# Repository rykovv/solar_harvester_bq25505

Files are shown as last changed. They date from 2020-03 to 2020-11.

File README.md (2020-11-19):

# Solar Harvester v1.0_m1

Solar harvesting power supply board based on TI BQ25505 PMIC with MPPT functionality configured for tracking 80% of the PV input. The board provides voltage/current measurement IC (INA226) intended for measurement of the PV input and a fuel gauge system based on MAX17040 IC to check and monitor battery state.

## Table of Contents ##

[[_TOC_]]

## Rev1 manufactured and assembled

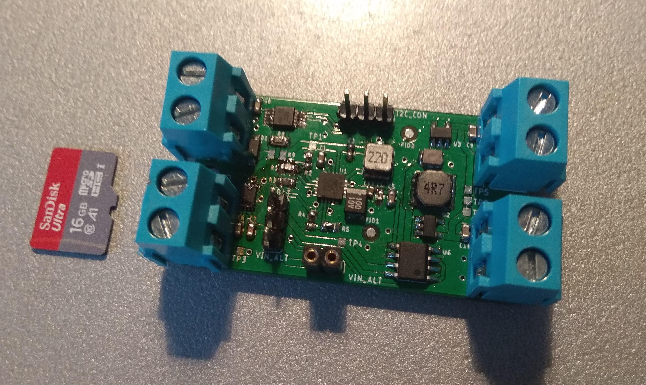
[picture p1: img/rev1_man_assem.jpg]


## Rev2 simulated

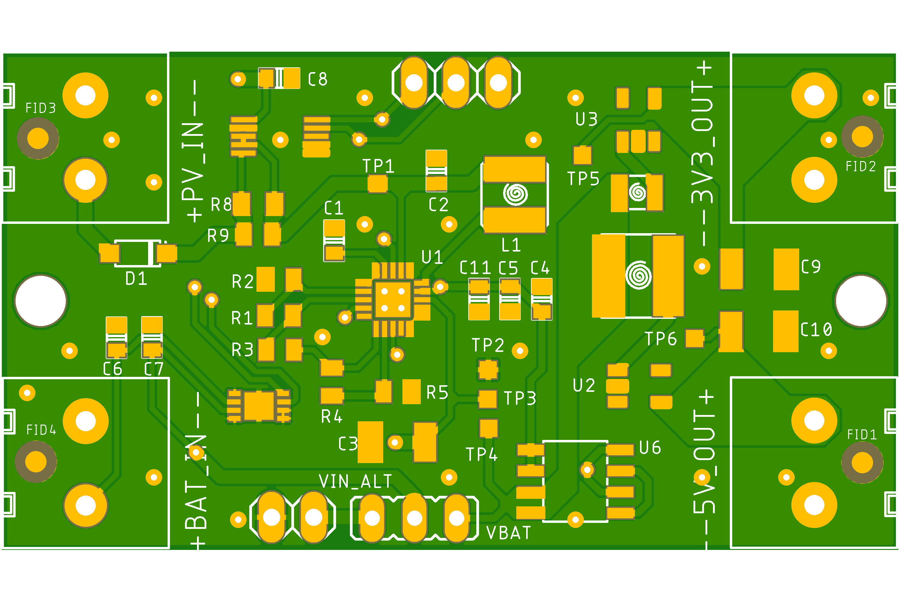
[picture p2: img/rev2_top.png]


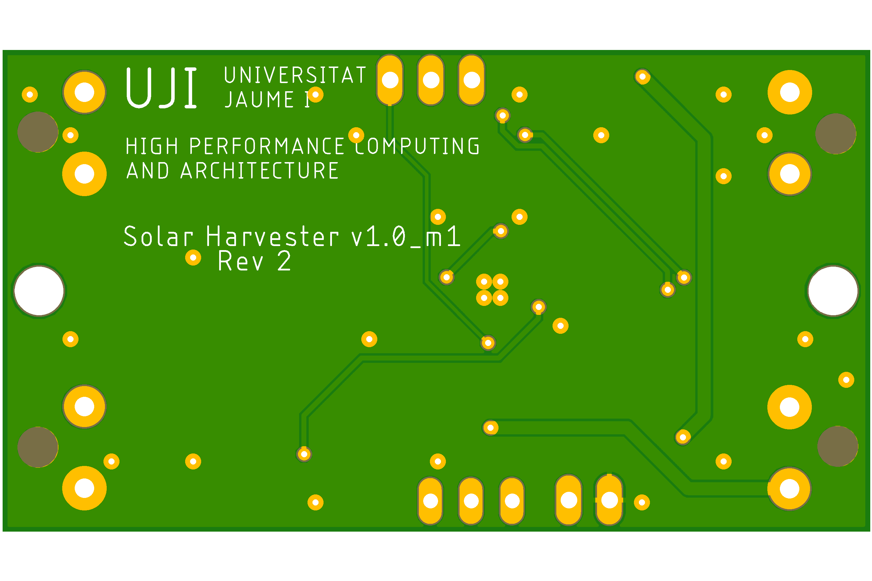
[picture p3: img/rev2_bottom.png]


## Detailed Overview

The BQ25505 was created for special needs of ultra low power applications. Therefore, it is designed for extract uW and mW of power generated from multiple energy harvesting sources. The board configuration suits only for solar power applications.

Once a PV pannel and Lipo battery are connected to the board and load capacitors are charged (>=1.8V) the main boost charger starts working extracting energy from the PV pannel. The ouput power is driven based on VBAT_OK threshold (3.3V) which is set based on R~ok1-3~ resistors. If the attached battery voltage is less then VBAT_OK, than only charging circuitry will work. This way the battery is saved from being damaged by undervoltage condition. Once the battery voltage rises up to VBAT_OK_HYST (3.7V), the load will be connected to the battery again. The BQ25505 provides overvoltage protection functionality set based on R~ov1,2~ resistors. That is, when the battery voltage reaches VBAT_OV voltage (4.2V) the main boost charger cease charging and only monitors voltage levels. Summing up, the BQ25505 will charge the storage element always unless its voltage is less than VBAT_OV. Refer to the Battery over-voltage, under-voltage and operating range section for examining concrete values calculation.

There is a possibility for supercap input energy storage instead of the Lipo battery. The maximum voltage for the supercap must be 5V. This modification implies changes in VBAT_OK, VBAT_OK_HYST, and VBAT_OV threasholds; and R~ok1-3~ resistors must be reselected accordingly. Refer to the BQ25505 datasheet to see corresponding formulas and equations (Section 8.2.1.2 Detailed Design Procedure).

Adjust CSTOR load capacitors depending on energy storage voltage. Remove C11 if VBAT_SEC < 3.0V.

## Specifications

Input:
 - PV panel 5V, 150mA
 - Lipo 3.7V battery

Output:
 - 3.3V, 1.2A
 - 5V, 1.8A

Maximum charging curerrent is 100mA.

## ICs
 - BQ25505
 - TPS613221A (3.3V)
 - TPS613222A (5V)
 - INA226
 - MAX17040
 - DMP3085LSD (dual pmos)

## Data Out - I^2^C
In order to extract information from the voltage/current measurement IC and the fuel gauge the proper I^2^C connection is needed. External pin headers fulfill this purpose. Note the internal I^2^C bus is **not pulled up**. Make sure the I^2^C bus from your main MCU board pulls up the bus.

## Battery over-voltage, under-voltage and operating range

### Over-voltage

Battery over-voltage protection is determined by R1 and R2 resistors according to 7.3.3

**VBAT_OV** = 3/2 * VBIAS * (1 + R1/R2)

Since, VBIAS is internally set to 1.21V, we have

VBAT_OV = 3/2 * 1.21V * (1 + 7.32M/5.62M) = **4.179V ~= 4.2V**

### Under-voltage

Battery under-voltage is internally set to 1.95V (see 7.3.2), hence being to suitable for the application, the push-pull multiplexer drivers (see 7.3.5) were used for the purpose. According to VBAT_OK and VBAT_OK_HYST values (see Operating range section).

### Operating range

The battery operating range is established by R3, R4, and R5 resistors which determine VBAT_OK and VBAT_OK_HYST values. According to the selected resistors values,

**VBAT_OK** = VBIAS * (1 + R4/R5) = 1.21V * (1 + 7.5M/4.3M) = **3.32V**

and

**VBAT_OK_HYST** = VBIAS * (1 + [R4 + R3]/R5) = 1.21V * (1 + [7.5M + 1.2M]/4.3M) = **3.658V**

## Issues

Despite all values of resistors R~ok1-3~ and R~ov1,2~ were correctly calculated (see 3.7V 860mAh Li-po battery and Battery over-voltage, under-voltage and operating range section) BQ25505 does not behave as expected and presents serious instabilities incompatible with deployment in real applications. When the battery is fully charged and attached, on one hand, and there is enough PV power input to start the circuitry, on the other hand, the BQ25505 starts working as expected until the battery is discharged (voltage below VBAT_OK). When the battery is half-discharged (voltage about VBAT_OK_HYST), and independently of the PV power input, VSTOR is unable to give stable output. What happens is when the 3.3V & 5V voltage regulators reach predefined output levels and the load starts to consume power (especially when the power is greater than 200mA, perhaps max transitory current in this state is much lower), the BQ25505 switches constantly on and off #VBAT_SEC_ON for a couple of milliseconds. It makes impossible to provide enough power for stable MCU launching.

A potential solution for this drawback is to substitute the current Under-voltage protection scheme with a battery management IC that would be in charge of over- and under-voltage protection.

## Revisions

### Rev 0
### Rev 1
 - Components with 0603 metric footprint were substituted by 0603 imperial
### Rev 2
 - Board size increased to 30x55
 - Changed C3 footprint to 3528, C4 and C11 to 1608
 - Changed C9 and C10 to 100u 3528
 - Rewired PCB
 - Components font size increased to 32mil

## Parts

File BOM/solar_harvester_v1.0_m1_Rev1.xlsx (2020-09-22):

Company: | University Jaume I |  |  |  | Project Name: | Solar Harvester v1.0_m1 |  | PCB Options :
Contact: | Vladislav Rykov |  |  |  | Order / Task:
Address: | Castellón - Spain Shippment: Castellón - Spain |  |  |  |  |  |  | PCB Size |  | 43.2 x 68.6mm
 |  |  |  |  |  |  |  | Layers: |  | 2
 |  |  |  |  |  |  |  | Thickness: |  | 1.6mm
 |  |  |  |  |  |  |  | Solder Mask Color: |  | Green
Tel: | +34 642411134 |  |  |  |  |  |  | Surface Finish: |  | HASL(Lead Free)
Email: | rykov@uji.es |  |  |  |  |  |  | Copper Weight: |  | 1oz.
# | Reference | Qty | Value | Manufacturer | MPN | Description | Package | SMD/THT | Pins /Pads per Component | Distributor | Distributor SKU | More Details
1 | JP1, JP4 | 2 |  | Amphenol Commercial Products | G800LQ305018EU | Headers & Wire Housings Pin Header 2.54mm Pitch STR DIP,1x3Pin |  | THT | 3 | Mouser | 523-G800LQ305018EU
2 | JP3 | 1 |  | Preci-dip | 801-87-002-10-001101 | Headers & Wire Housings |  | THT | 2 | Mouser | 437-8018700210001101
3 | R9 | 1 | 0 | Vishay / Dale | CRCW06030000Z0EAC | Thick Film Resistors 1/10Watt 0ohms Commercial Use |  | SMD | 2 | Mouser | 71-CRCW06030000Z0EAC
4 | C1, C7 | 2 | 0.01u | Wurth Elektronik | 885012206040 | Multilayer Ceramic Capacitors MLCC - SMD/SMT WCAP-CSGP 0.01uF 0603 10% 16V MLCC |  | SMD | 2 | Mouser | 710-885012206040
5 | C5, C8 | 2 | 0.1u | Wurth Elektronik | 885012206071 | Multilayer Ceramic Capacitors MLCC - SMD/SMT WCAP-CSGP 0.1uF 0603 10% 25V MLCC |  | SMD | 2 | Mouser | 710-885012206071
6 | C3 | 1 | 100u | AVX | F931A107KBA | Tantalum Capacitors - Solid SMD 10V 100uF 10% 1211 ESR= 1.2 Ohms |  | SMD | 2 | Mouser | 647-F931A107KBA
8 | C11 | 1 | 10u | Taiyo Yuden | JMK107ABJ106MA-T | Multilayer Ceramic Capacitors MLCC - SMD/SMT 10uF 6.3V X5R +/-20% 0603 Gen Purp |  | SMD | 2 | Mouser | 963-JMK107ABJ106MA-T
9 | R6 | 1 | 1k | Vishay / Dale | CRCW06031K00FKEAC | Thick Film Resistors 1/10Watt 1Kohms 1% Commercial Use |  | SMD | 2 | Mouser | 71-CRCW06031K00FKEAC
10 | C6 | 1 | 1u | Yageo | CC0603KRX5R8BB105 | Multilayer Ceramic Capacitors MLCC - SMD/SMT 1.0uF 25V X5R 10% |  | SMD | 2 | Mouser | 603-CC603KRX5R8BB105
11 | C9, C10 | 2 | 22u | Murata Electronics | GRM188R61A226ME15D | Multilayer Ceramic Capacitors MLCC - SMD/SMT 0603 22uF 10volts *Derate Voltage/Temp |  | SMD | 2 | Mouser | 81-GRM188R61A226ME5D
12 | L1 | 1 | 22u | Wurth Elektronik | 74404043220A | Fixed Inductors WE-LQS 4025 22uH 1.11A 200mOhms |  | SMD | 2 | Mouser | 710-74404043220A
13 | R8 | 1 | 2m | IRC / TT Electronics | LRCS0805-R56JT5 | Current Sense Resistors - SMD 0805 .56 Ohms 5% |  | SMD | 2 | Mouser | 756-LRCS0805-R56JT5
14 | C2, C4 | 2 | 4u7 | Taiyo Yuden | LMK105BBJ475MVLF | Multilayer Ceramic Capacitors MLCC - SMD/SMT 0402 10V 4.7uF 20% X5R |  | SMD | 2 | Mouser | 963-LMK105BBJ475MVLF
15 | L3 | 1 | 4u7 | Taiyo Yuden | MAMK2520T4R7M | Fixed Inductors 1008 4.7uH 260mOhms +/-20%Tol 1.3A HiCur |  | SMD | 2 | Mouser | 963-MAMK2520T4R7M
16 | L2 | 1 | 4u7 | Bournes | SRN5020TA-4R7M | Fixed Inductors 4.7uH 20% 2.4A |  | SMD | 2 | Mouser | 652-SRN5020TA-4R7M
17 | R2 | 1 | 5.62M | Vishay / Dale | CRCW06035M62FKEA | Thick Film Resistors - SMD 1/10watt 5.62Mohms 0.01 |  | SMD | 2 | Mouser | 71-CRCW06035M62FKEA
18 | R1 | 1 | 7.32M | Vishay / Dale | CRCW06037M32FKEA | Thick Film Resistors - SMD 1/10watt 7.32Mohms 0.01 |  | SMD | 2 | Mouser | 71-CRCW06037M32FKEA
19 | R3 | 1 | 1.2M | Vishay / Dale | CRCW06031M20FKEA | Thick Film Resistors - SMD 1/10watt 1.2Mohms 1% |  | SMD | 2 | Mouser | 71-CRCW06031M20FKEA
20 | R4 | 1 | 7.5M | Vishay / Dale | CRCW06037M50FKEA | Thick Film Resistors - SMD 1/10watt 7.5Mohms 1% |  | SMD | 2 | Mouser | 71-CRCW0603-7.5M-E3
21 | R5 | 1 | 4.3M | Vishay / Dale | CRCW06034M30FKEA | Thick Film Resistors - SMD 1/10watt 4.3Mohms 1% |  | SMD | 2 | Mouser | 71-CRCW06034M30FKEA
22 | U1 | 1 | BQ25505 | Texas Instruments | BQ25505RGRR | Battery Management Ultra Low Power Harvester Pwr Mgmt |  | SMD | 21 | Mouser | 595-BQ25505RGRR
23 | 3V3_OUT, 5V_OUT, BAT_IN, PV_IN | 4 |  | CUI Devices | TB007-508-02BE | Fixed Terminal Blocks Terminal block, screw type, 5.08, PCB mount |  | THT | 2 | Mouser | 490-TB007-508-02BE
24 | U6 | 1 | DMP3085LSD | Diodes Incorporated | DMP3085LSD-13 | MOSFET P-Ch ENH FET -30V 70mOhm -10V -3.9A |  | SMD | 8 | Mouser | 621-DMP3085LSD-13
25 | U5 | 1 | INA226 | Texas Instruments | INA226AIDGSR | Current & Power Monitors & Regulators Hi-Side Msmt,Bi-Dir Current/Pwr Mon | MSOP-10 / VSSOP | SMD | 10 | Mouser | 595-INA226AIDGSR
26 | D1 | 1 | SD101CW RH | Taiwan Semiconductor | SD101CW RH | Schottky Diodes & Rectifiers 15mA 50 Volt 400mW |  | SMD | 2 | Mouser | 821-SD101CWRH
27 | U4 | 1 | MAX17040 | Maxim Integrated | MAX17040G+T | Battery Management Compact, Low-Cost 1S/2S Fuel Gauges | 8 TDFN-EP | SMD | 9 | Mouser | 700-MAX17040G+T
28 | U2 | 1 | TPS613222ADBVR | Texas Instruments | TPS613222ADBVR | IC REG BOOST 5V 2.5A SOT23-5 | SOT23-5 | SMD | 5 | Mouser | 595-TPS613222ADBVR
29 | U3 | 1 | TPS613221ADBVR | Texas Instruments | TPS613221ADBVR | IC REG BOOST 3.3V 1.6A SOT23-5 | SOT23-5 | SMD | 5 | Mouser | 595-TPS613221ADBVR
28
 |  |  |  |  |  |  | THT | 7 | 16
 |  |  |  | *Generic parts can be replaced for other components with same features. The MPN is additional information. |  |  | SMD | 29 | 104
 |  |  |  |  |  |  | TOTAL | 36 | 120

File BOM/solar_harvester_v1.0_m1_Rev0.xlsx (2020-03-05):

Company: | University Jaume I |  |  |  | Project Name: | Solar Harvester v1.0_m1 |  | PCB Options :
Contact: | Vladislav Rykov |  |  |  | Order / Task:
Address: | Castellón - Spain Shippment: Castellón - Spain |  |  |  |  |  |  | PCB Size |  | 43.2 x 68.6mm
 |  |  |  |  |  |  |  | Layers: |  | 2
 |  |  |  |  |  |  |  | Thickness: |  | 1.6mm
 |  |  |  |  |  |  |  | Solder Mask Color: |  | Green
Tel: | +34 642411134 |  |  |  |  |  |  | Surface Finish: |  | HASL(Lead Free)
Email: | rykov@uji.es |  |  |  |  |  |  | Copper Weight: |  | 1oz.
# | Reference | Qty | Value | Manufacturer | MPN | Description | Package | SMD/THT | Pins /Pads per Component | Distributor | Distributor SKU | More Details
1 | JP1, JP4 | 2 |  | Amphenol Commercial Products | G800LQ305018EU | Headers & Wire Housings Pin Header 2.54mm Pitch STR DIP,1x3Pin |  | THT | 3 | Mouser | 523-G800LQ305018EU
2 | JP3 | 1 |  | Preci-dip | 801-87-002-10-001101 | Headers & Wire Housings |  | THT | 2 | Mouser | 437-8018700210001101
3 | R9 | 1 | 0 | Vishay / Dale | CRCW02010000Z0ED | Thick Film Resistors - SMD 1/20watt ZEROohm Jumper 0603 |  | SMD | 2 | Mouser | 71-CRCW02010000Z0ED
4 | C1 | 1 | 0.01u | Murata Electronics | GRM033R71A103KA01D | Multilayer Ceramic Capacitors MLCC - SMD/SMT 0201 0.01uF 10volts X7R 10% |  | SMD | 2 | Mouser | 81-GRM033R71A103KA1D
5 | C5, C8 | 2 | 0.1u | Taiyo Yuden | LMK063C6104MP-F | Multilayer Ceramic Capacitors MLCC - SMD/SMT 10V 0.1uF 20% X6S 0603 |  | SMD | 2 | Mouser | 963-LMK063C6104MP-F
6 | C3 | 1 | 100u | AVX | F931A107KBA | Tantalum Capacitors - Solid SMD 10V 100uF 10% 1211 ESR= 1.2 Ohms |  | SMD | 2 | Mouser | 647-F931A107KBA
7 | C7 | 1 | 10n | Murata Electronics | GRM033R71A103KA01D | Multilayer Ceramic Capacitors MLCC - SMD/SMT 0201 0.01uF 10volts X7R 10% |  | SMD | 2 | Mouser | 81-GRM033R71A103KA1D
8 | C11 | 1 | 10u | Murata Electronics | ZRB15XR61A106ME01D | Multilayer Ceramic Capacitors MLCC - SMD/SMT |  | SMD | 2 | Mouser | 81-ZRB15XR61A106ME1D
9 | R6 | 1 | 1k | Panasonic | ERJ-1GNF1001C | Thick Film Resistors - SMD 1Kohm 1% HalogenFree AEC-Q200 0603 |  | SMD | 2 | Mouser | 667-ERJ-1GNF1001C
10 | C6 | 1 | 1u | Murata Electronics | GRM033R60J105ME11J | Multilayer Ceramic Capacitors MLCC - SMD/SMT 1UF 6.3V 20% 0603 |  | SMD | 2 | Mouser | 81-GRM033R60J105ME1J
11 | C9, C10 | 2 | 22u | Murata Electronics | GRM188R61A226ME15D | Multilayer Ceramic Capacitors MLCC - SMD/SMT 0603 22uF 10volts *Derate Voltage/Temp |  | SMD | 2 | Mouser | 81-GRM188R61A226ME5D
12 | L1 | 1 | 22uH | WURTH ELEKTRONIK | 74404043220A | FIXED IND 22UH 1.11A |  | SMD | 2 | Mouser | 710-74404043220A
13 | R8 | 1 | 2m | IRC / TT Electronics | LRCS0805-R56JT5 | Current Sense Resistors - SMD 0805 .56 Ohms 5% |  | SMD | 2 | Mouser | 756-LRCS0805-R56JT5
14 | C2, C4 | 2 | 4u7 | Taiyo Yuden | LMK105BBJ475MVLF | Multilayer Ceramic Capacitors MLCC - SMD/SMT 0402 10V 4.7uF 20% X5R |  | SMD | 2 | Mouser | 963-LMK105BBJ475MVLF
15 | L3 | 1 | 4u7 | Taiyo Yuden | MAMK2520T4R7M | FIXED IND 4.7UH 1.3A 260 MOHM |  | SMD | 2 | Mouser | 963-MAMK2520T4R7M
16 | L2 | 1 | 4u7 | Bournes | SRN5020TA-4R7M | FIXED IND 4.7UH 2.4A 60MOHM |  | SMD | 2 | Mouser | 652-SRN5020TA-4R7M
17 | R2 | 1 | 5.62M | KOA Speer | RK73H1HTTC5624F | Thick Film Resistors - SMD 1/20W 5.62M OHM 1% 200PPM |  | SMD | 2 | Mouser | 660-RK73H1HTTC5624F
18 | R1, R3, R4, R5 | 4 | 7.32M | Vishay / Dale | CRCW02017M32FNED | Thick Film Resistors - SMD 7.32M OHM 1% |  | SMD | 2 | Mouser | 71-CRCW02017M32FNED
19 | U1 | 1 | BQ25505 | Texas Instruments | BQ25505RGRR | Battery Management Ultra Low Power Harvester Pwr Mgmt |  | SMD | 21 | Mouser | 595-BQ25505RGRR
20 | 3V3_OUT, 5V_OUT, BAT_IN, PV_IN | 4 |  | CUI Devices | TB007-508-02BE | Fixed Terminal Blocks Terminal block, screw type, 5.08, PCB mount |  | THT | 2 | Mouser | 490-TB007-508-02BE
21 | U6 | 1 | DMP3085LSD | Diodes Incorporated | DMP3085LSD-13 | MOSFET P-Ch ENH FET -30V 70mOhm -10V -3.9A |  | SMD | 8 | Mouser | 621-DMP3085LSD-13
22 | U5 | 1 | INA226 | Texas Instruments | INA226AIDGSR | Current & Power Monitors & Regulators Hi-Side Msmt,Bi-Dir Current/Pwr Mon | MSOP-10 / VSSOP | SMD | 10 | Mouser | 595-INA226AIDGSR
23 | D1 | 1 | JDH2S02SL | Toshiba | JDH2S02SL,L3F | Schottky Diodes & Rectifiers High Freq Schottky .01A 10V |  | SMD | 2 | Mouser | 757-JDH2S02SLL3F
24 | U4 | 1 | MAX17040 | Maxim Integrated | MAX17040G+T | Battery Management Compact, Low-Cost 1S/2S Fuel Gauges | 8 TDFN-EP | SMD | 9 | Mouser | 700-MAX17040G+T
25 | U2 | 1 | TPS613222ADBVR | Texas Instruments | TPS613222ADBVR | IC REG BOOST 5V 2.5A SOT23-5 | SOT23-5 | SMD | 5 | Mouser | 595-TPS613222ADBVR
26 | U3 | 1 | TPS613221ADBVR | Texas Instruments | TPS613221ADBVR | IC REG BOOST 3.3V 1.6A SOT23-5 | SOT23-5 | SMD | 5 | Mouser | 595-TPS613221ADBVR
26
 |  |  |  |  |  |  | THT | 7 | 16
 |  |  |  | *Generic parts can be replaced for other components with same features. The MPN is additional information. |  |  | SMD | 29 | 104
 |  |  |  |  |  |  | TOTAL | 36 | 120

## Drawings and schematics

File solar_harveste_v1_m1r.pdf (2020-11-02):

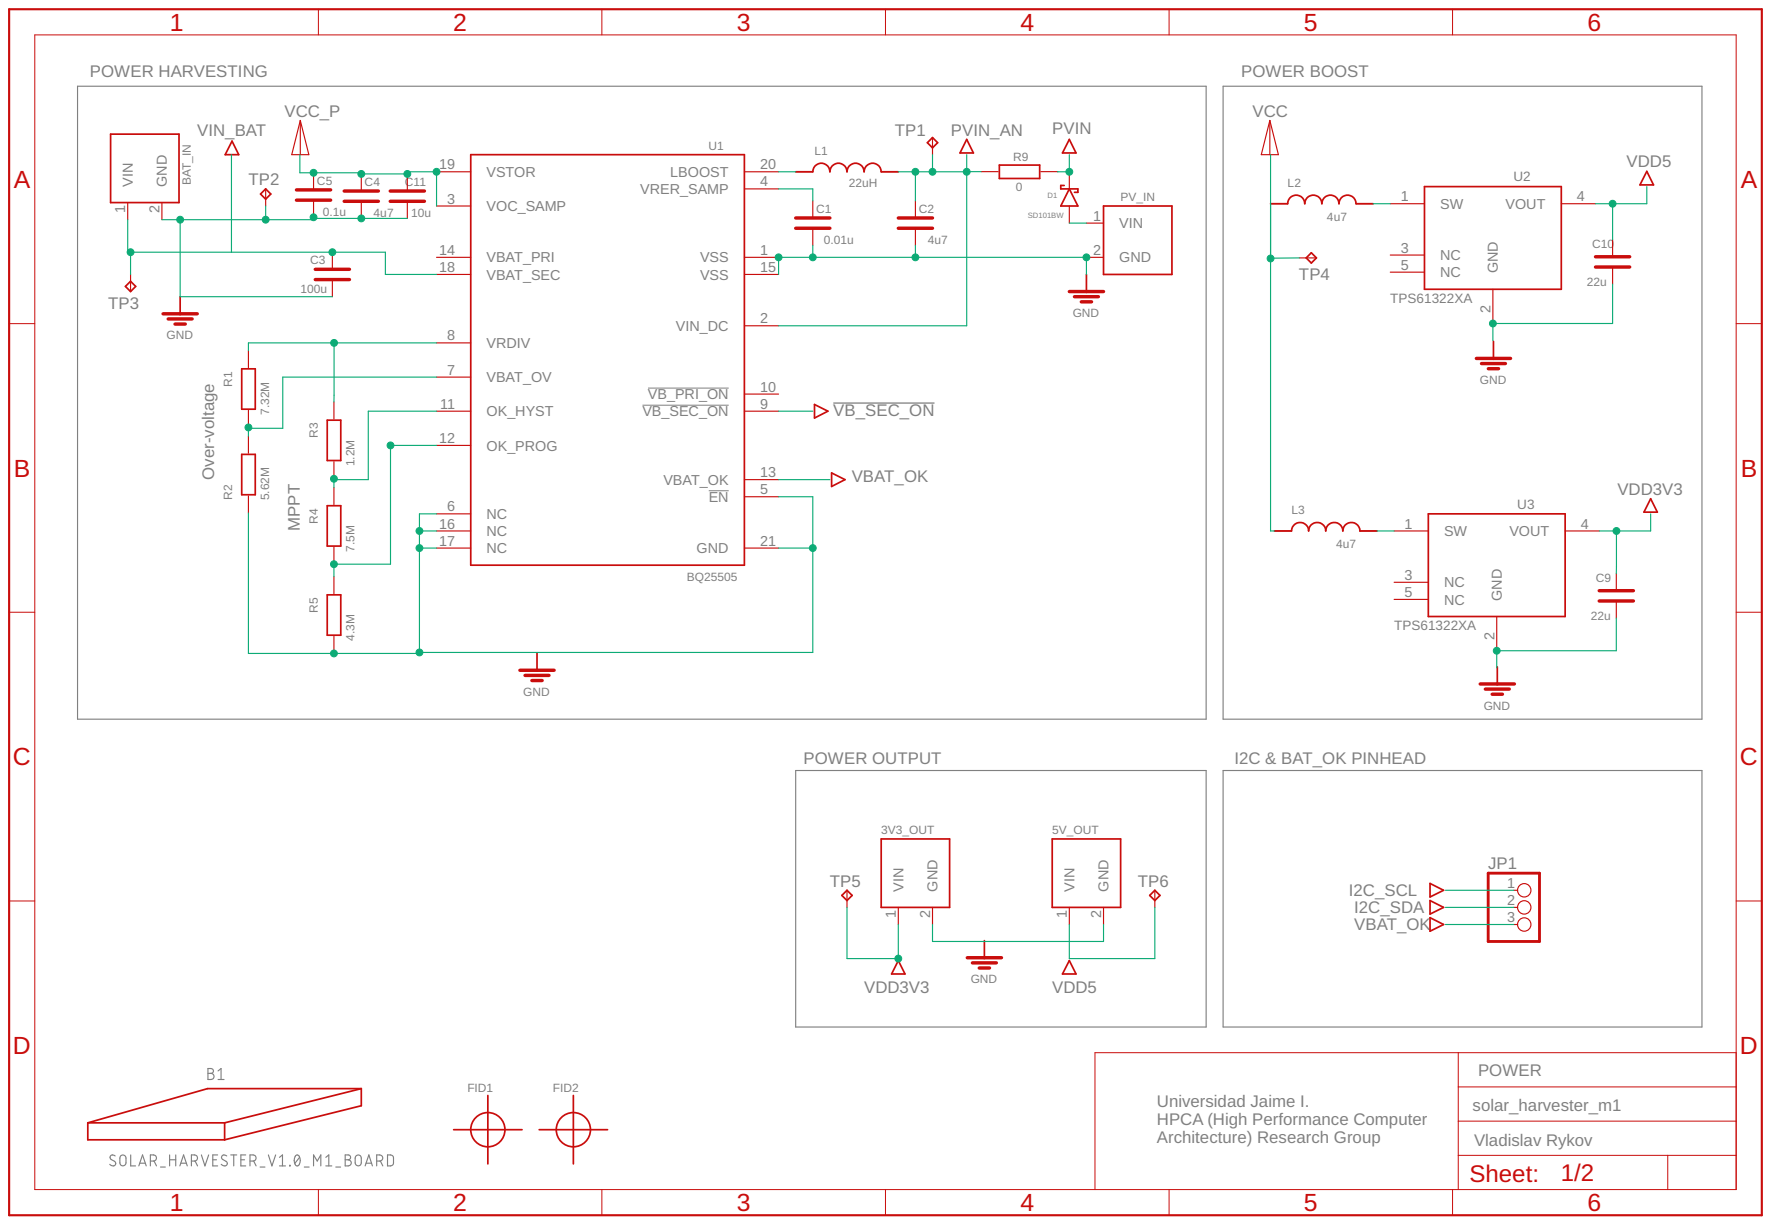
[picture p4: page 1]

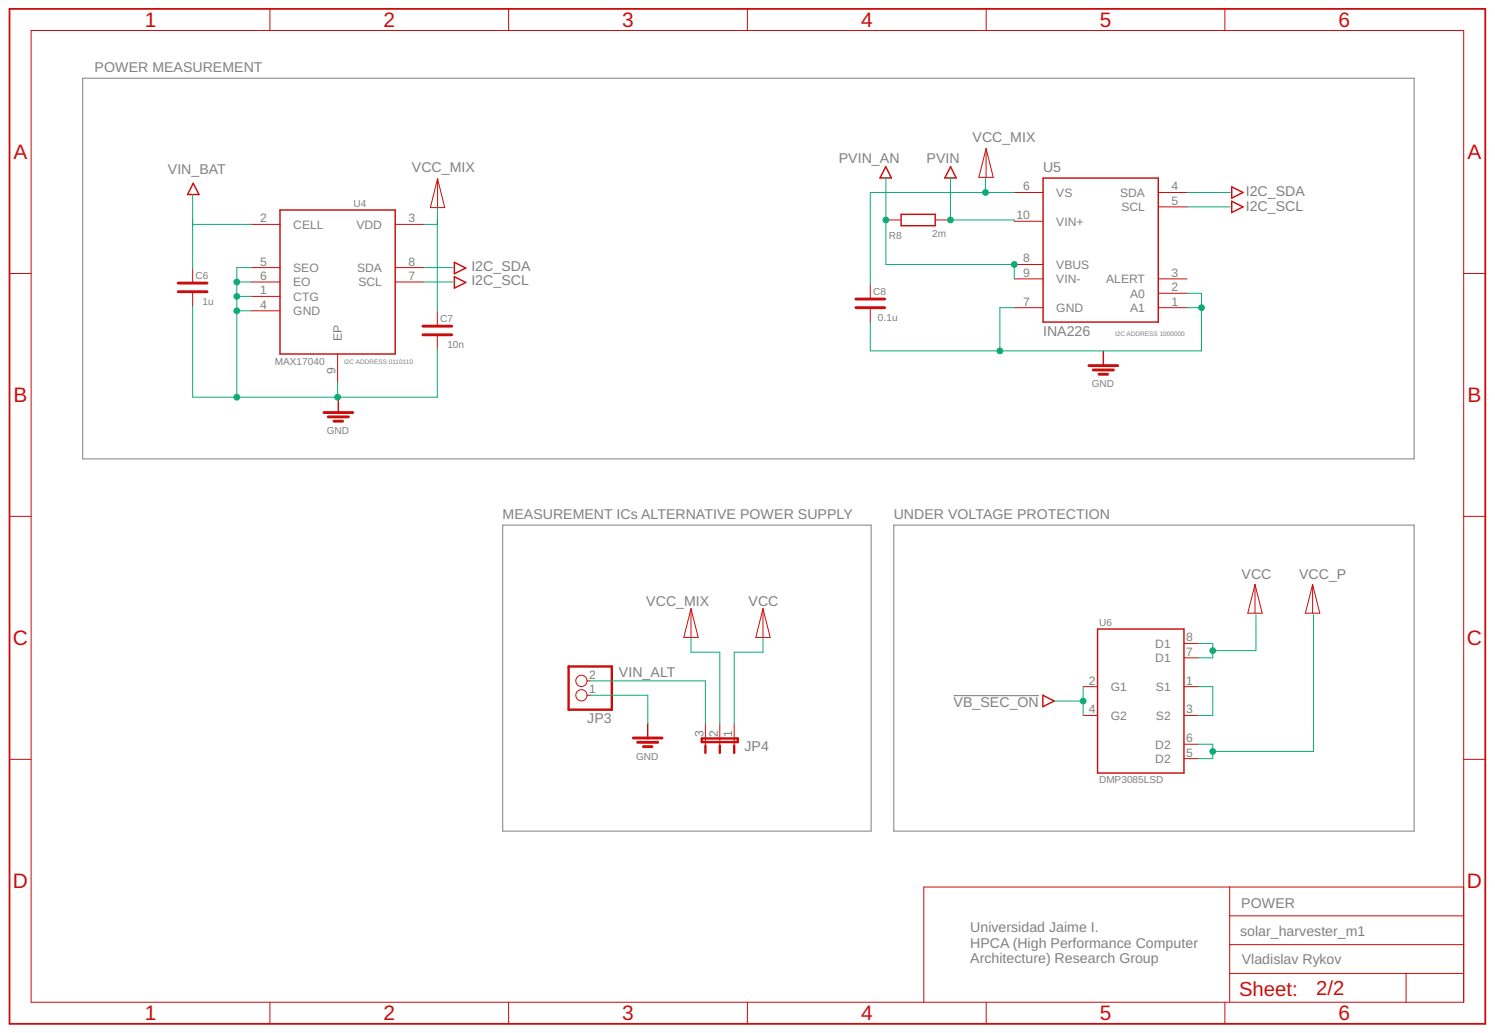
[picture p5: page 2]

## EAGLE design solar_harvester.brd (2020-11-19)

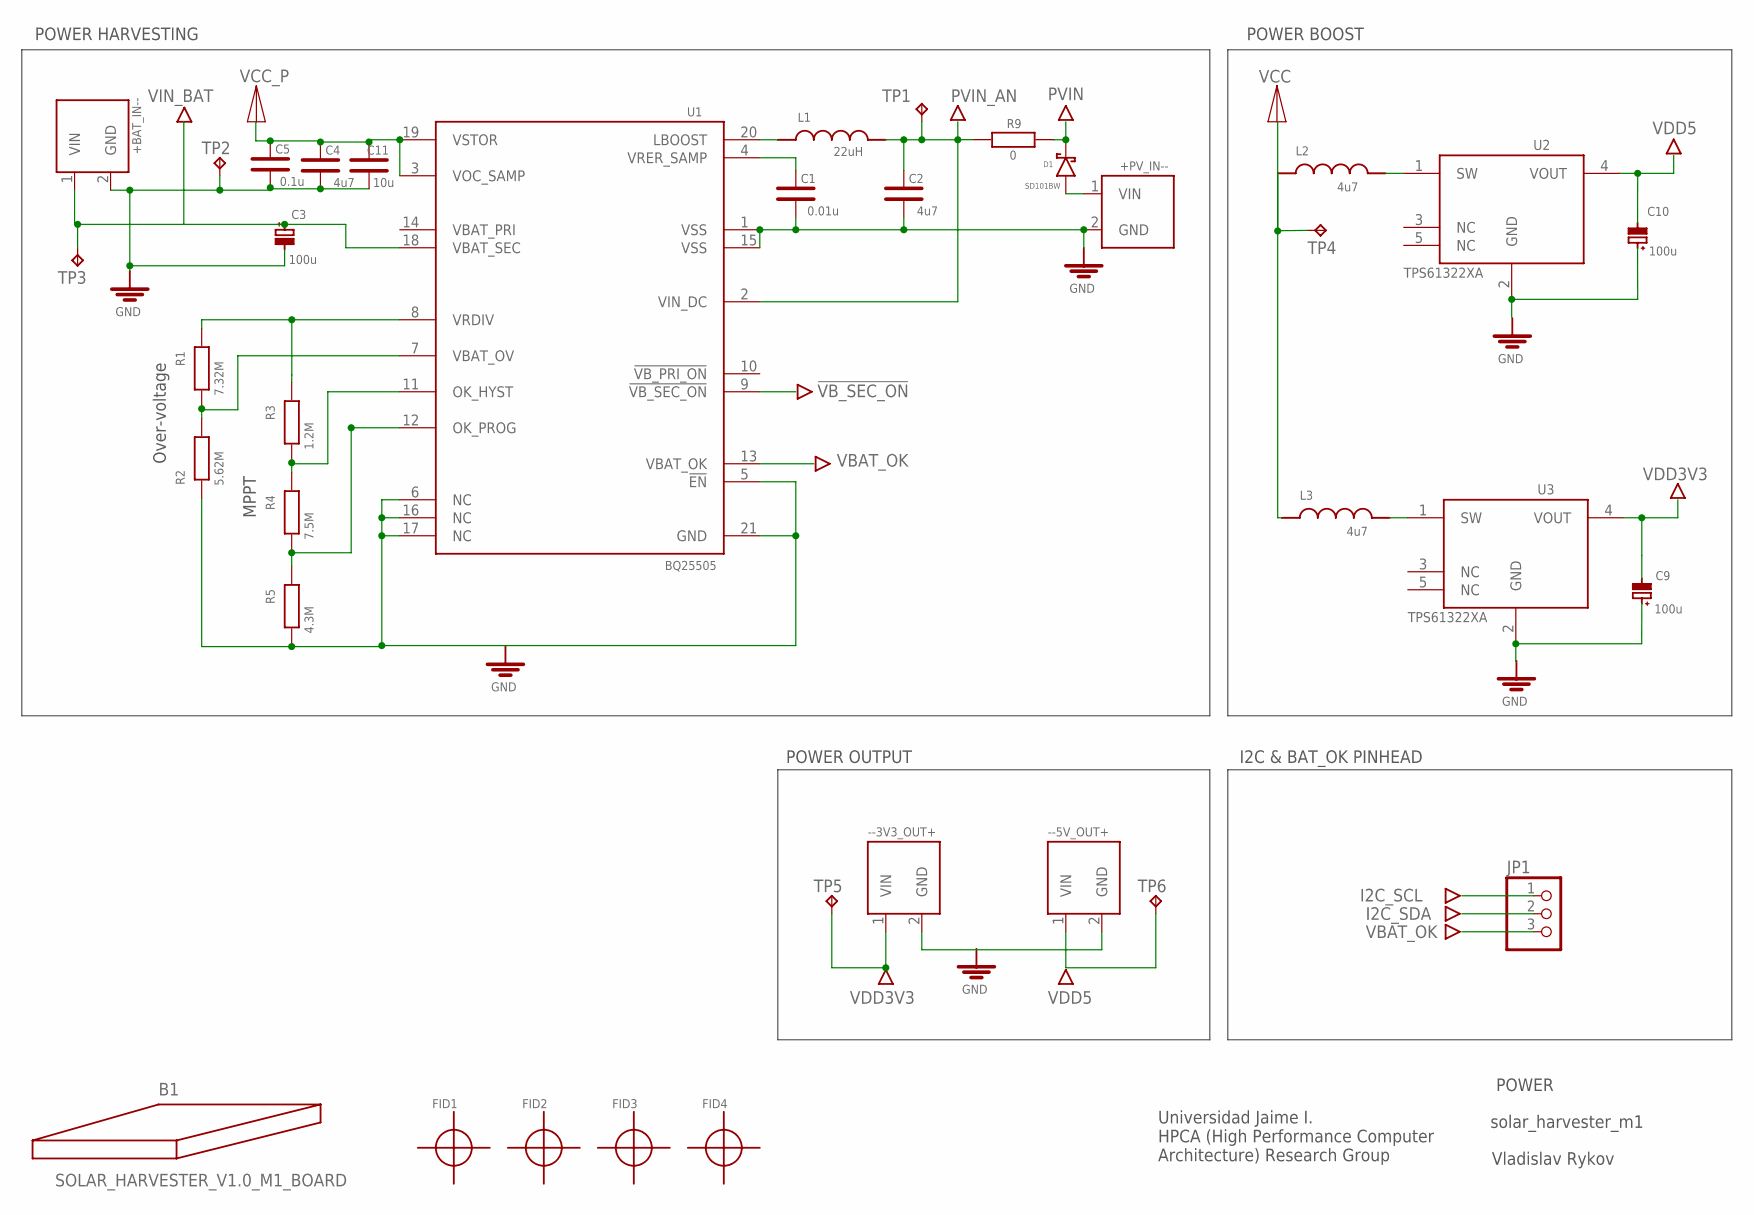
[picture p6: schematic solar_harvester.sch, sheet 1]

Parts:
+BAT_IN--: CONN_SCEW_TYPE_2P; CONN_SCREW_TYPE_2P
+PV_IN--: CONN_SCEW_TYPE_2P; CONN_SCREW_TYPE_2P
--3V3_OUT+, --5V_OUT+: CONN_SCEW_TYPE_2P; CONN_SCREW_TYPE_2P
B1: SOLAR_HARVESTER_V1.0_M1_BOARD; SOLAR_HARVESTER_V1.0_M1_FOOTPRINT
C1: 0.01u; 1608_FOOTPRINT
C2, C4: 4u7; 1608_FOOTPRINT
C3, C9, C10: 100u; 3528_TAN_FOOTPRINT
C5: 0.1u; 1608_FOOTPRINT
C11: 10u; 1608_FOOTPRINT
D1: SD101BW; SOD-123
FID1, FID2, FID3, FID4: FIDUCIAL_25
JP1: PINHD-1X3; 1X03
L1: 22uH; FIXED_4040_FOOTPRINT
L2: 4u7; FIXED_5050_FOOTPRINT
L3: 4u7; FIXED_2520_FOOTPRINT
R1: 7.32M; RESISTOR_1608_FOOTPRINT
R2: 5.62M; RESISTOR_1608_FOOTPRINT
R3: 1.2M; RESISTOR_1608_FOOTPRINT
R4: 7.5M; RESISTOR_1608_FOOTPRINT
R5: 4.3M; RESISTOR_1608_FOOTPRINT
R9: 0; RESISTOR_1608_FOOTPRINT
TP1, TP2, TP3, TP4, TP5, TP6: TPTP10SQ; TP10SQ
U1: BQ25505; BQ25505_FOOTPRINT
U2, U3: TPS61322XA; TPS61322XA_FOOTPRINT

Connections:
!VB_SEC_ON!: U1.9 (!VB_SEC_ON!); also elsewhere on the board
GND: +BAT_IN--.2 (GND), +PV_IN--.2 (GND), --3V3_OUT+.2 (GND), --5V_OUT+.2 (GND), C1.2, C2.2, C3.2, C4.2, C5.2, C9.1, C10.1, C11.2, R2.1, R5.1, TP2.TP, U1.1 (VSS), U1.5 (!EN!), U1.6 (NC), U1.15 (VSS), U1.16 (NC), U1.17 (NC), U1.21 (GND), U2.2 (GND), U3.2 (GND); also elsewhere on the board
I2C_SCL: JP1.1; also elsewhere on the board
I2C_SDA: JP1.2; also elsewhere on the board
unnamed: L1.1, U1.20 (LBOOST)
unnamed: C1.1, U1.4 (VRER_SAMP)
unnamed: R1.2, R3.2, U1.8 (VRDIV)
unnamed: R1.1, R2.2, U1.7 (VBAT_OV)
unnamed: R3.1, R4.2, U1.11 (OK_HYST)
unnamed: R4.1, R5.2, U1.12 (OK_PROG)
unnamed: +PV_IN--.1 (VIN), D1.2
unnamed: L3.2, U3.1 (SW)
unnamed: L2.2, U2.1 (SW)
PVIN: D1.1, R9.2; also elsewhere on the board
PVIN_AN: C2.1, L1.2, R9.1, TP1.TP, U1.2 (VIN_DC); also elsewhere on the board
VBAT_OK: JP1.3, U1.13 (VBAT_OK)
VCC: L2.1, L3.1, TP4.TP; also elsewhere on the board
VCC_P: C4.1, C5.1, C11.1, U1.3 (VOC_SAMP), U1.19 (VSTOR); also elsewhere on the board
VDD3V3: --3V3_OUT+.1 (VIN), C9.2, TP5.TP, U3.4 (VOUT)
VDD5: --5V_OUT+.1 (VIN), C10.2, TP6.TP, U2.4 (VOUT)
VIN_BAT: +BAT_IN--.1 (VIN), C3.1, TP3.TP, U1.18 (VBAT_SEC); also elsewhere on the board

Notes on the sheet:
POWER HARVESTING
POWER BOOST
POWER
solar_harvester_m1
Universidad Jaime I. HPCA (High Performance Computer Architecture) Research Group
Vladislav Rykov
I2C & BAT_OK PINHEAD
POWER OUTPUT
Over-voltage
MPPT

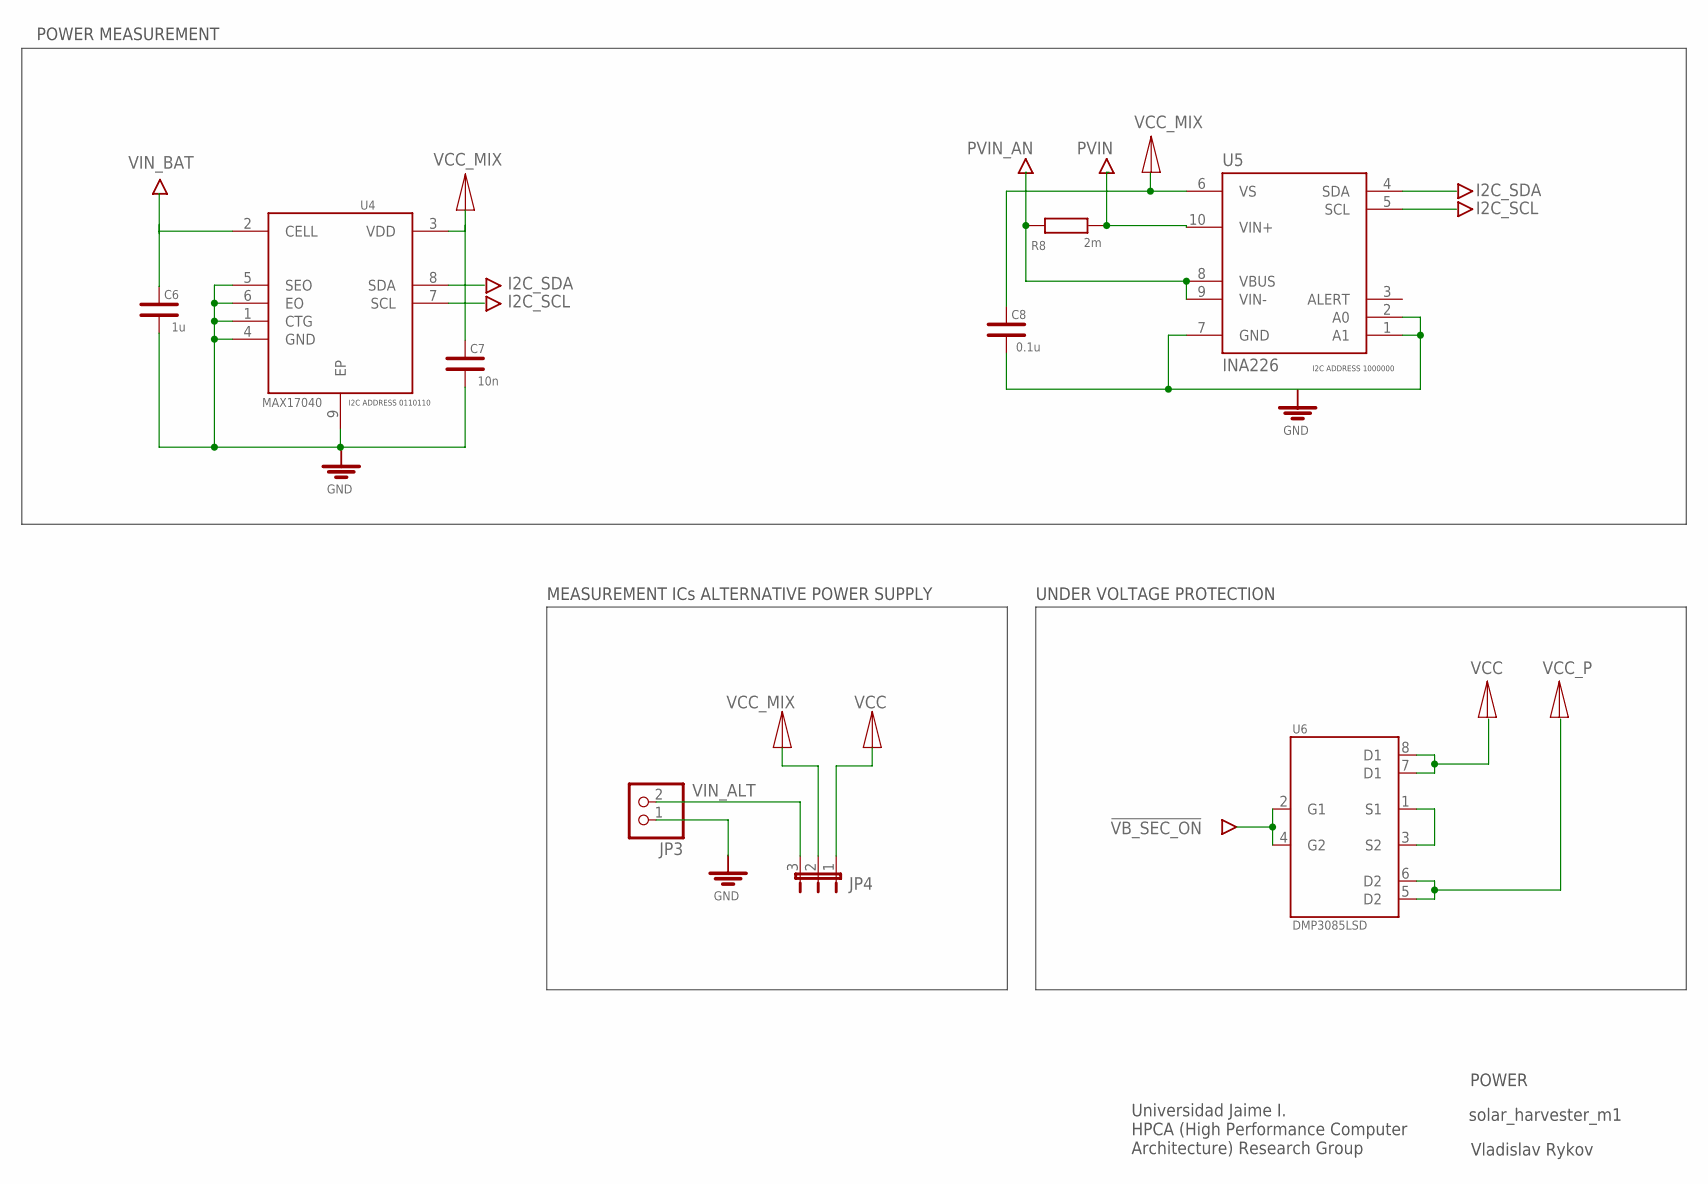
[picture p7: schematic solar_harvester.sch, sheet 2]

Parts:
C6: 1u; 1608_FOOTPRINT
C7: 10n; 1608_FOOTPRINT
C8: 0.1u; 1608_FOOTPRINT
JP3: PINHD-1X2; 1X02
JP4: JP2E; JP2
R8: 2m; RESISTOR_2012_FOOTPRINT
U4: MAX17040; MAX17040G+T_FOOTPRINT
U5: INA226; INA226_FOOTPRINT
U6: DMP3085LSD; SO-8

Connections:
!VB_SEC_ON!: U6.2 (G1), U6.4 (G2); also elsewhere on the board
GND: C6.2, C7.2, C8.2, JP3.1, U4.1 (CTG), U4.4 (GND), U4.5 (SEO), U4.6 (EO), U4.9 (EP), U5.1 (A1), U5.2 (A0), U5.7 (GND); also elsewhere on the board
I2C_SCL: U4.7 (SCL), U5.5 (SCL); also elsewhere on the board
I2C_SDA: U4.8 (SDA), U5.4 (SDA); also elsewhere on the board
unnamed: U6.1 (S1), U6.3 (S2)
PVIN: R8.2, U5.10 (VIN+); also elsewhere on the board
PVIN_AN: R8.1, U5.8 (VBUS), U5.9 (VIN-); also elsewhere on the board
VCC: JP4.1, U6.7 (D1), U6.8 (D1); also elsewhere on the board
VCC_MIX: C7.1, C8.1, JP4.2, U4.3 (VDD), U5.6 (VS)
VCC_P: U6.5 (D2), U6.6 (D2); also elsewhere on the board
VIN_ALT: JP3.2, JP4.3
VIN_BAT: C6.1, U4.2 (CELL); also elsewhere on the board

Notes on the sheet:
I2C ADDRESS 1000000
POWER
solar_harvester_m1
POWER MEASUREMENT
I2C ADDRESS 0110110
Universidad Jaime I. HPCA (High Performance Computer Architecture) Research Group
Vladislav Rykov
UNDER VOLTAGE PROTECTION
MEASUREMENT ICs ALTERNATIVE POWER SUPPLY

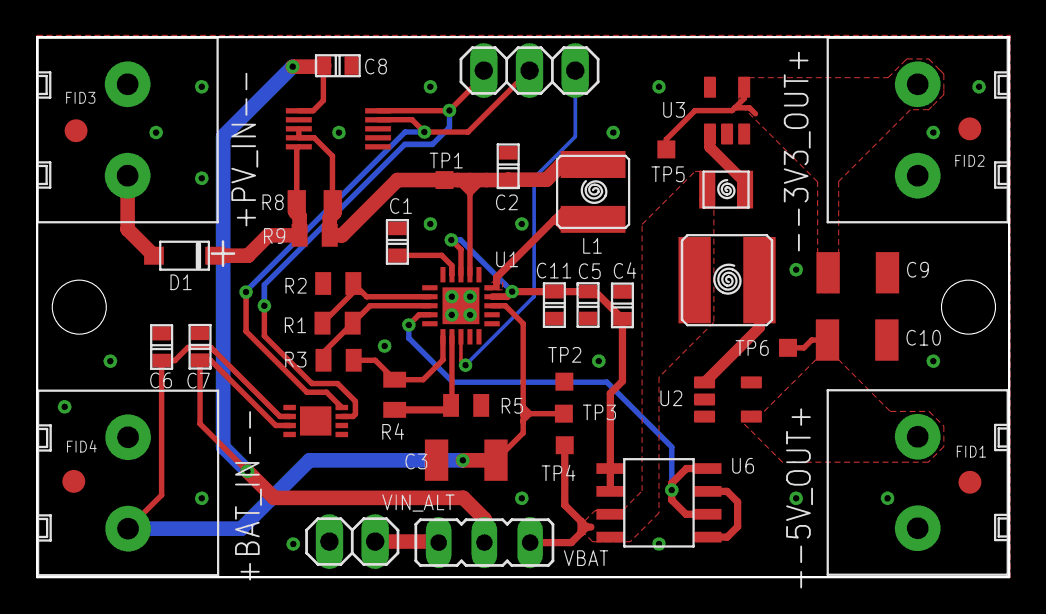
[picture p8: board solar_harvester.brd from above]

Board: 2 copper layers, 54.0 x 30.0 mm, 46 parts (0 on the bottom side), 24 nets.

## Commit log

2019-11-27 schematic complete v01. Caps and diode selection needed
    [solar_harvester.sch]
2019-11-28 board routing started
    [solar_harvester.brd, solar_harvester.sch]
2019-11-29 bq25505, both tps622, max17004 routed
    [solar_harvester.brd, solar_harvester.sch]
2019-12-02 routing complete without battery under-voltage protection
    [solar_harvester.brd, solar_harvester.sch]
2019-12-02 resized board, routing almost finished
    [solar_harvester.brd, solar_harvester.sch]
2019-12-02 Routing done, without uv protection
    [solar_harvester.brd, solar_harvester.sch]
2019-12-02 uv added schematic
    [solar_harvester.brd, solar_harvester.sch]
2019-12-02 uv routed done
    [solar_harvester.brd, solar_harvester.sch]
2019-12-03 readme added
    [solar_harvester.brd]
2019-12-03 checked pad sizes, embellished board
    [solar_harvester.brd, solar_harvester.sch]
2019-12-11 tps, fids added, todo:rev gnd, pass grc
    [solar_harvester.brd, solar_harvester.sch]
2019-12-11 alt measurement ics vin added, drc & gnd rev done
    [solar_harvester.brd, solar_harvester.sch]
2019-12-13 input power signs added
    [solar_harvester.brd]
2019-12-16 final BOM Rev0 composed, layout adjust
    Some caps sizes were changed due to vol/dimension issues
    [Copy of BomTemplate.xls, solar_harvester.brd, solar_harvester.sch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]
2020-01-15 BOM revised, gerbers generated
    [mouser copy-paste.xlsx, solar_harvester.brd, solar_harvester_v1.0_m1_Rev0.xlsx]
2020-01-21 desc minor modif
    [mouser copy-paste.xlsx]
2020-03-05 increase comps sizes -> pcb reruting (in progress)
    [solar_harvester.brd, solar_harvester.sch, solar_harvester_v1.0_m1_Rev0.xlsx]
2020-03-05 rerouting finished
    [solar_harvester.brd, solar_harvester.sch]
2020-03-09 Rev 1 done. todo: bom update
    [solar_harvester.brd]
2020-03-09 BOM updated
    [solar_harvester.brd, solar_harvester.sch, solar_harvester_v1.0_m1_Rev1.xlsx]
2020-09-22 BOM+gerbers update, DESC added
    [solar_harvester_v1.0_m1_Rev1.xlsx]
2020-11-02 readme.md extended after assembling & testing
